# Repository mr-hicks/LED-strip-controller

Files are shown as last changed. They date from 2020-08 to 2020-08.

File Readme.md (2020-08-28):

# What
A 2 channel LED strip  controller that uses as PWM signal generated by a microcontroller.

**Features**
  
  * TinyPico µC (ESP32)
  * 2 independent channels
  * Sink about 10A per channel, 5A easily
  * 12V for LED strips
  * µC or manual control
  * Manual control can be placed where-ever (6 pin ribbon connection) optional 2 USB charging ports
  * Can control multiple boards in parallel with on µC for distributed systems

# Credit
<iframe width="560" height="315" src="https://www.youtube.com/embed/DhbMnQt14_o" frameborder="0" allow="accelerometer; autoplay; encrypted-media; gyroscope; picture-in-picture" allowfullscreen></iframe>

But, I wanted it to be self setting time wise so that it could automatically come on in the morning or off in the evening.

# Sections
## Power
Two input options, dc barrel or bare wire.
Barrel is intended for lower power smaller applications (I'm intending lamps), bare wire for higher power.  Example, light fixture.

Then a fuse and a 1k and 14V zener in parallel.
The resistor is a bleeder for capacitors.
The zener is to protect the caps from overvoltage.

## PWM

## 

# Other stuff

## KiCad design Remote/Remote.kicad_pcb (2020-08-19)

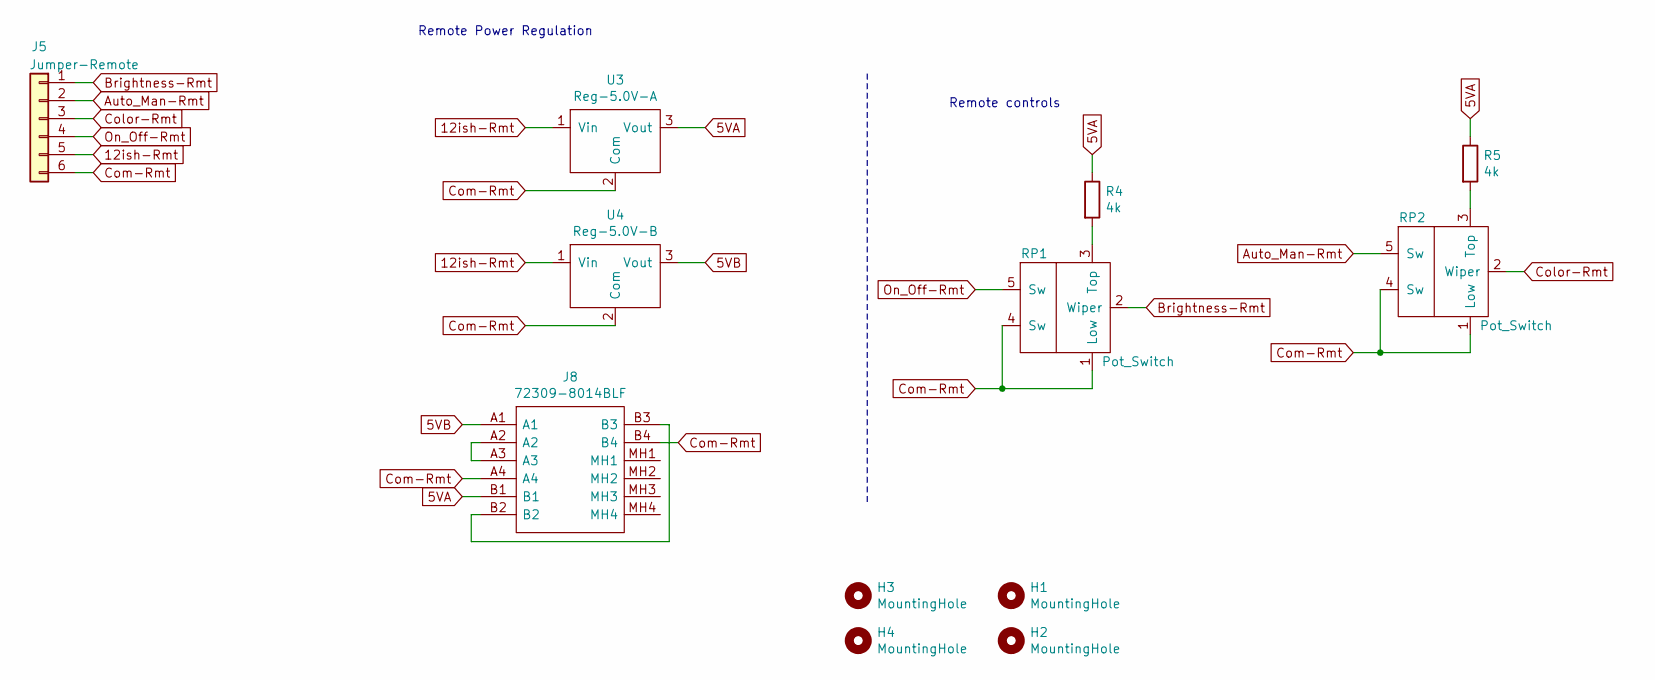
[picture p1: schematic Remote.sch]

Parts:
H1, H2, H3, H4: MountingHole; MountingHole_2.2mm_M2_Pad
J5: Jumper-Remote; 21787106
J8: 72309-8014BLF; 723098014BLF; Mouser Part Number 649-72309-8014BLF
R4, R5: 4k; R_Axial_DIN0204_L3.6mm_D1.6mm_P5.08mm_Horizontal
RP1, RP2: Pot_Switch; pot_switch
U3: Reg-5.0V-A; 5.0V-Reg
U4: Reg-5.0V-B; 5.0V-Reg

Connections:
5VA: J8.B1, R4.1, R5.1, U3.3 (Vout)
5VB: J8.A1, U4.3 (Vout)
12ish-Rmt: J5.5, U3.1 (Vin), U4.1 (Vin)
Auto_Man-Rmt: J5.2, RP2.5 (Sw)
Brightness-Rmt: J5.1, RP1.2 (Wiper)
Color-Rmt: J5.3, RP2.2 (Wiper)
Com-Rmt: J5.6, J8.A4, J8.B4, RP1.1 (Low), RP1.4 (Sw), RP2.1 (Low), RP2.4 (Sw), U3.2 (Com), U4.2 (Com)
unnamed: J8.A2, J8.A3
unnamed: J8.B2, J8.B3
unnamed: R4.2, RP1.3 (Top)
unnamed: R5.2, RP2.3 (Top)
On_Off-Rmt: J5.4, RP1.5 (Sw)

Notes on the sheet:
Remote Power Regulation
Remote controls

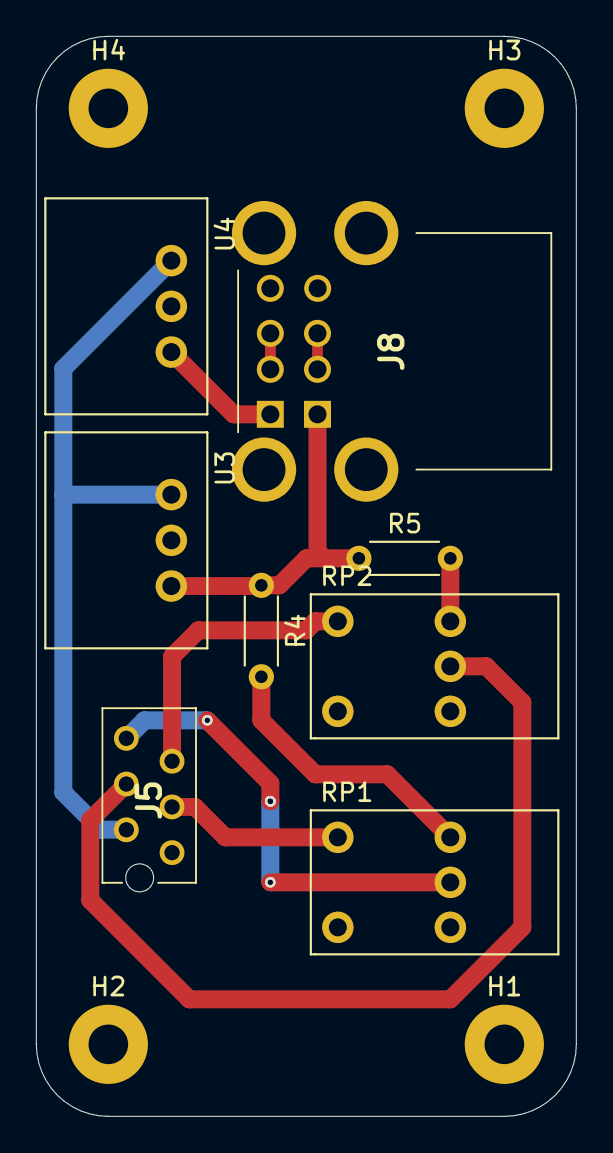
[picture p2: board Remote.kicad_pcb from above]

Board: 2 copper layers, 30.0 x 60.0 mm, 12 parts (0 on the bottom side), 12 nets.

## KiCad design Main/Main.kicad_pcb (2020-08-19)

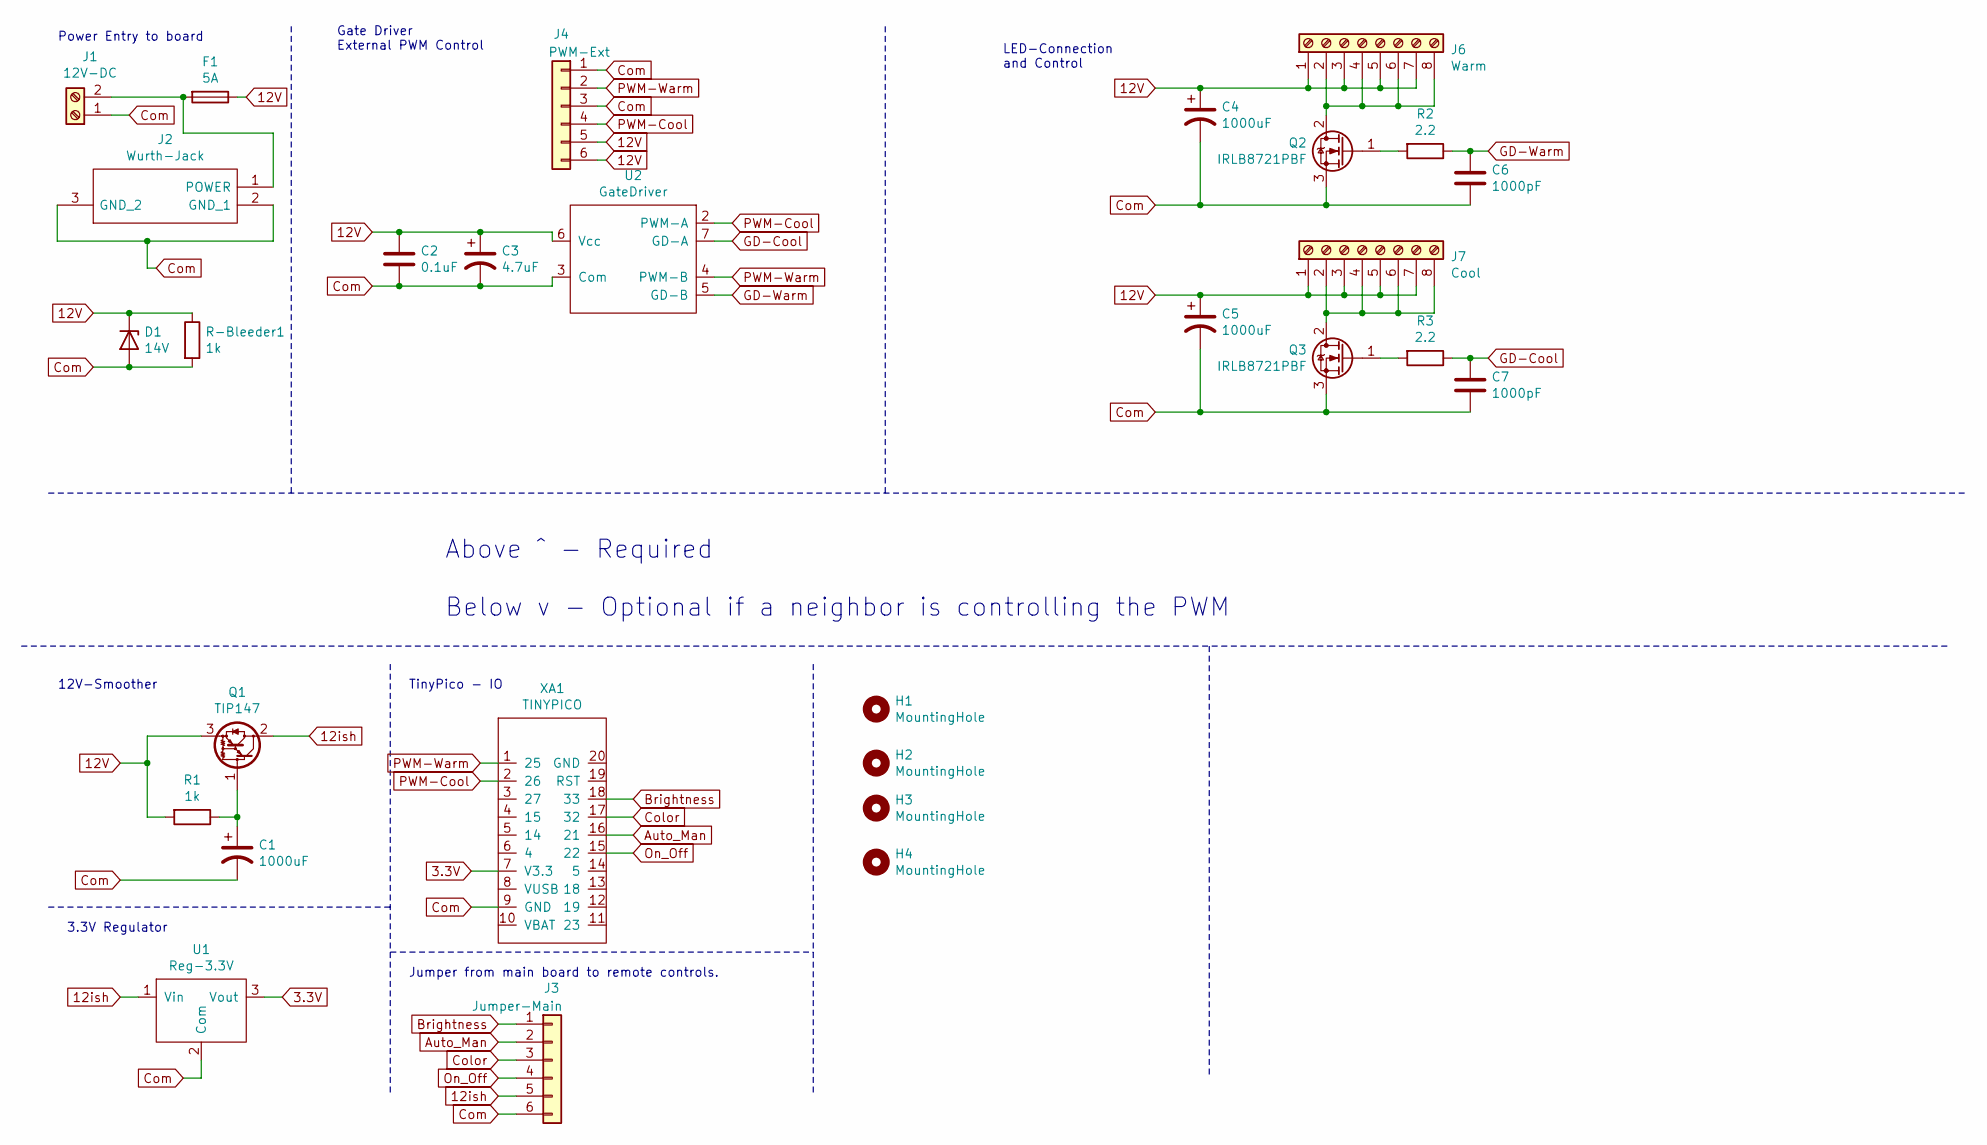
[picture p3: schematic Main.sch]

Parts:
C1, C4, C5: 1000uF; CP_Radial_D10.0mm_P5.00mm
C2: 0.1uF; C_Rect_L7.2mm_W2.5mm_P5.00mm_FKS2_FKP2_MKS2_MKP2
C3: 4.7uF; CP_Radial_D5.0mm_P2.00mm
C6, C7: 1000pF; C_Rect_L7.2mm_W2.5mm_P5.00mm_FKS2_FKP2_MKS2_MKP2
D1: 14V; D_DO-35_SOD27_P7.62mm_Horizontal
F1: 5A; 4527
H1, H2, H3, H4: MountingHole; MountingHole_2.2mm_M2_Pad
J1: 12V-DC; CUI_TBL005A-500-02GY-2WT
J2: Wurth-Jack; 694106301002_1; Mouser Part Number 710-694106301002
J3: Jumper-Main; 21787106
J4: PWM-Ext; 21787106
J6: Warm; CUI_TBL005A-500-08GY-2WT
J7: Cool; CUI_TBL005A-500-08GY-2WT
Q1: TIP147; TO-220-3_Vertical
Q2, Q3: IRLB8721PBF; TO-220-3_Vertical
R1: 1k; R_Axial_DIN0204_L3.6mm_D1.6mm_P5.08mm_Horizontal
R2, R3: 2.2; R_Axial_DIN0207_L6.3mm_D2.5mm_P7.62mm_Horizontal
R-Bleeder1: 1k; R_Axial_DIN0204_L3.6mm_D1.6mm_P5.08mm_Horizontal
U1: Reg-3.3V; 3.3V-Reg
U2: GateDriver; DIP-8_W7.62mm_Socket
XA1: TINYPICO; _usr_TINYPICO

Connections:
3.3V: U1.3 (Vout), XA1.7 (V3.3)
12V: C2.1, C3.1, C4.1, C5.1, D1.1 (K), F1.1, J4.5, J4.6, J6.1, J6.3, J6.5, J6.7, J7.1, J7.3, J7.5, J7.7, Q1.3 (E), R1.2, R-Bleeder1.1, U2.6 (Vcc)
12ish: J3.5, Q1.2 (C), U1.1 (Vin)
Auto_Man: J3.2, XA1.16 (21)
Brightness: J3.1, XA1.18 (33)
Color: J3.3, XA1.17 (32)
Com: C1.2, C2.2, C3.2, C4.2, C5.2, C6.2, C7.2, D1.2 (A), J1.1, J2.2 (GND_1), J2.3 (GND_2), J3.6, J4.1, J4.3, Q2.3 (S), Q3.3 (S), R-Bleeder1.2, U1.2 (Com), U2.3 (Com), XA1.9 (GND)
GD-Cool: C7.1, R3.1, U2.7 (GD-A)
GD-Warm: C6.1, R2.1, U2.5 (GD-B)
unnamed: C1.1, Q1.1 (B), R1.1
unnamed: F1.2, J1.2, J2.1 (POWER)
unnamed: J6.2, J6.4, J6.6, J6.8, Q2.2 (D)
unnamed: J7.2, J7.4, J7.6, J7.8, Q3.2 (D)
unnamed: Q2.1 (G), R2.2
unnamed: Q3.1 (G), R3.2
On_Off: J3.4, XA1.15 (22)
PWM-Cool: J4.4, U2.2 (PWM-A), XA1.2 (26)
PWM-Warm: J4.2, U2.4 (PWM-B), XA1.1 (25)

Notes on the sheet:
Power Entry to board
Gate Driver External PWM Control
LED-Connection and Control
12V-Smoother
3.3V Regulator
Jumper from main board to remote controls.
TinyPico - IO
Above ^ - Required Below v - Optional if a neighbor is controlling the PWM

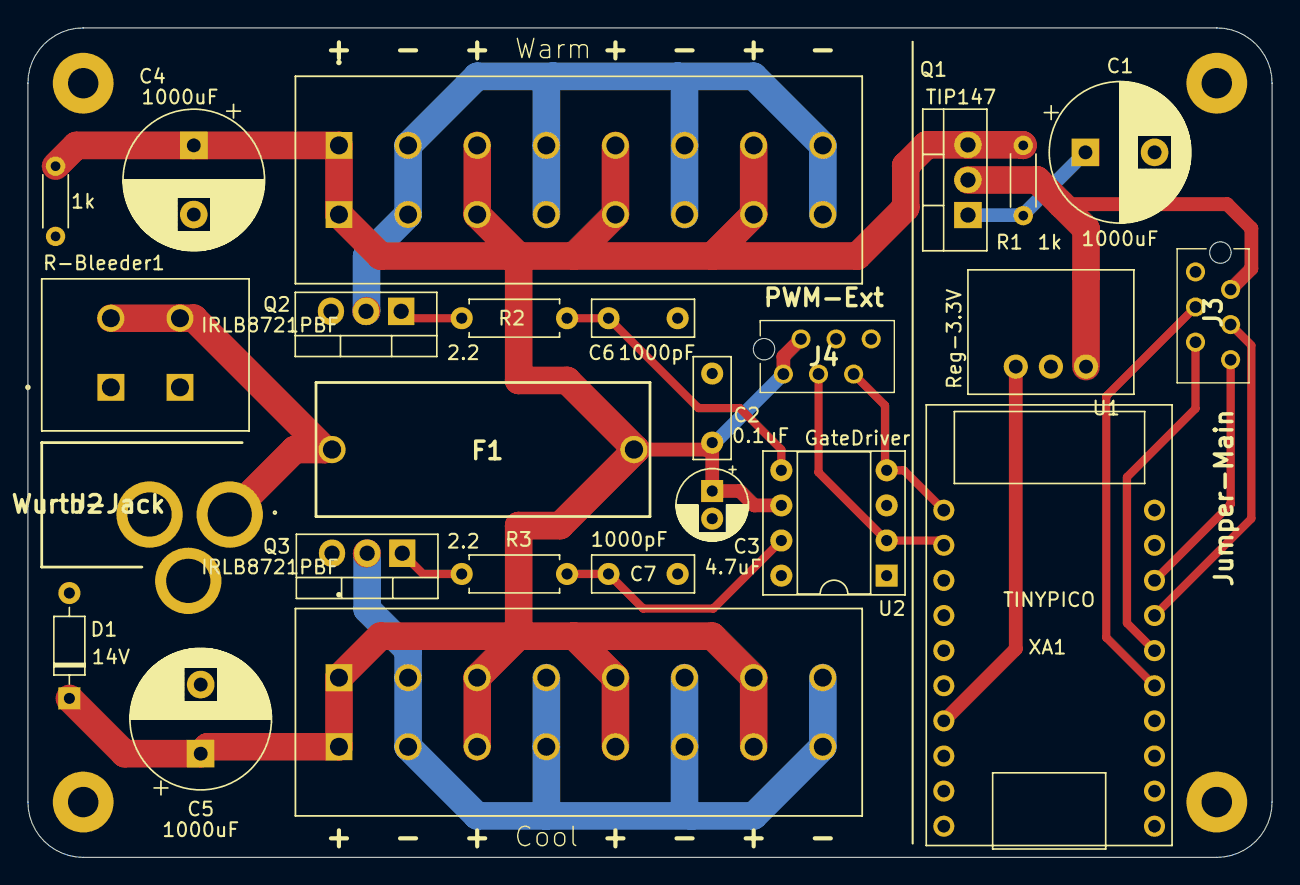
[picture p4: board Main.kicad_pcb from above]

Board: 2 copper layers, 90.0 x 60.0 mm, 29 parts (0 on the bottom side), 18 nets.

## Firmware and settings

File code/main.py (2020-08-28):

from machine import SPI, Pin
import tinypico as TinyPICO
from dotstar import DotStar
import time
import random
import micropython

# Configure SPI for controlling the DotStar
# Internally we are using software SPI for this as the pins being used are not hardware SPI pins
spi = SPI(sck=Pin(TinyPICO.DOTSTAR_CLK), mosi=Pin(
    TinyPICO.DOTSTAR_DATA), miso=Pin(TinyPICO.SPI_MISO))
# Create a DotStar instance
dotstar = DotStar(spi, 1, brightness=0.5)  # Just one DotStar, half brightness
# Turn on the power to the DotStar
TinyPICO.set_dotstar_power(True)

# Say hello
print("\nHello from TinyPICO!")
print("--------------------\n")

# Show some info on boot
print("Battery Voltage is {}V".format(TinyPICO.get_battery_voltage()))
print("Battery Charge State is {}\n".format(TinyPICO.get_battery_charging()))

# Show available memory
print("Memory Info - micropython.mem_info()")
print("------------------------------------")
micropython.mem_info()

# Create a colour wheel index int
color_index = 0

# Rainbow colours on the Dotstar
while True:
    # Get the R,G,B values of the next colour
    r, g, b = TinyPICO.dotstar_color_wheel(color_index)
    # Set the colour on the dotstar
    dotstar[0] = (r, g, b, 0.5)
    # Increase the wheel index
    color_index += 1
    # Sleep for 20ms so the colour cycle isn't too fast
    time.sleep_ms(20)

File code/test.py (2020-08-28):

from machine import SPI, Pin, ADC
import tinypico as TinyPICO
from dotstar import DotStar
import time
import utime
import random
import micropython
from ntptime import settime


def do_connect():
    import network
    wlan = network.WLAN(network.STA_IF)
    wlan.active(True)
    if not wlan.isconnected():
        print('reading out the ssid and password')
        with open('wifi_info.txt', 'r') as file:
            ssid, pswrd = file.read().split('\n')
            print('retrieved the ssid and password')

        print('connecting to network...')
        wlan.connect(ssid, pswrd)
        while not wlan.isconnected():
            pass
    print('network config:', wlan.ifconfig())


def get_time():
    settime()

    local_time_sec = utime.time() - 5 * 3600
    local_time = utime.localtime(local_time_sec)

    print(local_time)

    return(local_time)


    # Say hello
print("\nHello from TinyPICO!")
print("--------------------\n")

# connect to the wifi
do_connect()

# ntptime sets the clock from
get_time()


# setup the pins
# on pin
pin_on = Pin(22, Pin.IN, Pin.PULL_UP)
# when switch off - value is 1
# when switch on  - value is 0 (pulled down to ground)

# auto/manual pin
pin_am = Pin(21, Pin.IN, Pin.PULL_UP)

# test for GPIO pins
if False:
    i = 0
    while i < 10:
        i += 1
        print(pin_on.value())
        time.sleep(1)


# brightness adc - 33
adc_bright = ADC(Pin(33))
adc_bright.atten(ADC.ATTN_0DB)
adc_bright.width(ADC.WIDTH_12BIT)

# color adc pin - 32

# test for ADC pin
if True:
    i = 0
    t0 = time.time()
    while i < 10:
        i += 1
        avg = 0
        for counter in range(10):
            avg += adc_bright.read()

            time.sleep(0.1)

        print(avg / (4096 * 10))
        # print(time.time() - t0)
        # t0 = time.time()
        time.sleep(1)


# PWM warm pin - 25


# PWM cool pin - 26

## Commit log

2020-08-19 Upload work
    [Main-B_Mask.gbr, Main-Back.gbr, Main-Edge_Cuts.gbr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]
2020-08-28 testing ADC, GPIO
